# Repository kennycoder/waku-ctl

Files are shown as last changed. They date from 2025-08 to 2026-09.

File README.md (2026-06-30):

# waku-ctl - The open source water cooling controller.

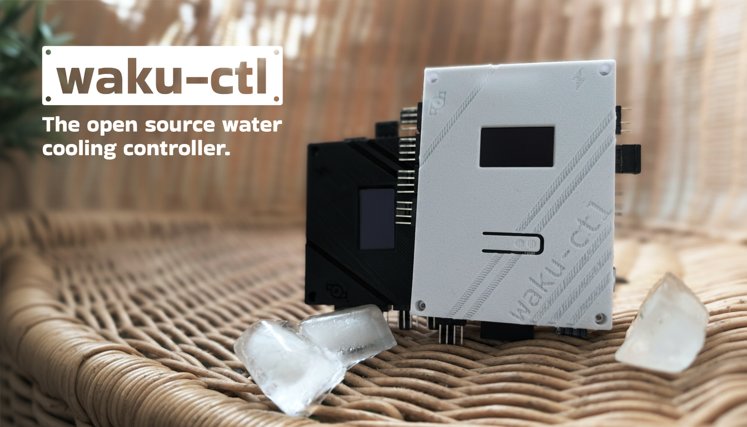
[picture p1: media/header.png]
waku-ctl banner


waku-ctl is an open-source water cooling controller designed to give you ultimate command over your custom water loop, freeing you from the limitations of BIOS profiles and proprietary software.

This project contains the hardware and software for the waku-ctl device.

## Support the Project

If you find waku-ctl useful, please consider supporting its development through a small donation. Your support will help grow the project and bring new features to life!

## How to get an assembled board

I'm happy to assemble a board for you for a fee, just drop me a message via email at me[at]nikolai[dot]one.

## Features

*   **Web Interface:** A user-friendly web interface for configuration and monitoring.
*   **Fan Control:**
    *   Control up to 4 fans/pumps.
    *   Customizable fan curves based on temperature readings.
    *   PID controller for precise temperature management.
    *   Set alarms for fan RPM and temperature thresholds.
    *   Configure step up/down duration for smooth fan speed transitions.
    *   Option to halt the PC on alarm conditions.
*   **Temperature Monitoring:**
    *   Supports three temperature sensors.
    *   Possibility to use deltas between sensors
    *   Display temperatures in Celsius or Fahrenheit.
*   **ARGB Lighting Control:**
    *   Control two separate ARGB headers.
    *   Multiple lighting effects: Static, 2-color wave, 2-color moving, and rainbow.
    *   Pass-through mode from an external ARGB source.
    *   Adjust effect speed and the number of LEDs.
*   **Connectivity:**
    *   WiFi connectivity with support for offline (Access Point) mode.
    *   MQTT support for telemetry data.
    *   USB-CDC daemon for HWiNFO64 integration.
*   **On-device Display:**
    *   OLED screen to display system status, temperatures, fan speeds, and RGB modes.
*   **Hardware:**
    *   Open-source PCB and 3D printable case design.
    *   Based on the powerful ESP32-S3 microcontroller.

## Structure

*   `/pcb`: Contains the PCB design files from Altium.
*   `/case`: Contains the STL files for the 3D printable case.
*   `/src`: Contains the source code for the ESP32 firmware.
*   `/data`: Contains the web interface files.
*   `/usb-cdc-daemon`: Contains a small system tray daemon that reads data via USB and submits it to HWiNFO64.

The firmware is developed using Visual Studio Code with the PlatformIO extension.

## Building the Firmware

1.  Install [Visual Studio Code](https://code.visualstudio.com/).
2.  Install the [PlatformIO IDE extension](https://platformio.org/platformio-ide) from the Visual Studio Code marketplace.
3.  Clone this repository.
4.  Open the cloned repository folder in Visual Studio Code.
5.  PlatformIO will automatically detect the `platformio.ini` file and install the necessary dependencies.
6.  Click the "Build" button in the PlatformIO toolbar (the checkmark icon) to compile the firmware.
7.  Click the "Upload" button (the right arrow icon) to flash the firmware to your connected ESP32-S3 board.
8.  Click "Build Filesystem Image" and "Upload Filesystem Image"
9.  Reset the device and connect to its access point under the name of "waku-ctl" to finish setup.

## Building the USB CDC tray daemon for HWInfo64 integration

1.  Install [golang](https://go.dev/doc/install)
2.  Enter `usb-cdc-daemon` folder and run `go build .`
3.  Execute the binary and check HWInfo64, you should start getting telemetry

### PCB layout

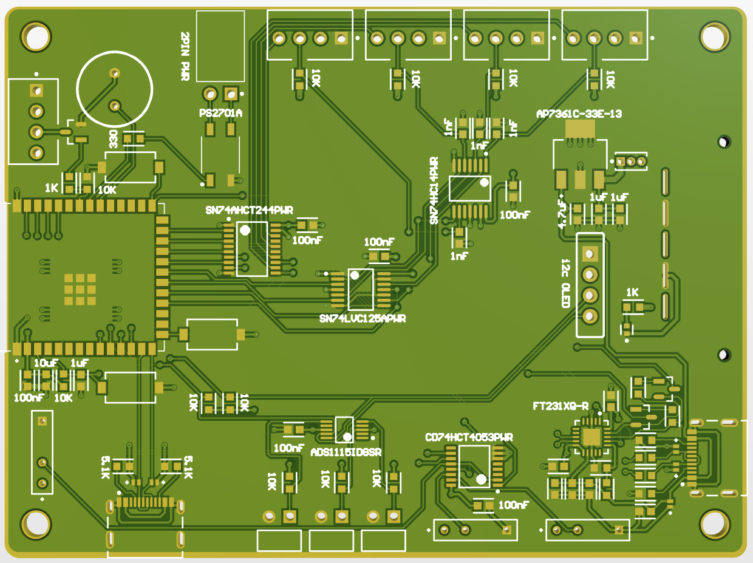
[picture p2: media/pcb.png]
waku-ctl pcb


### PCB schematic

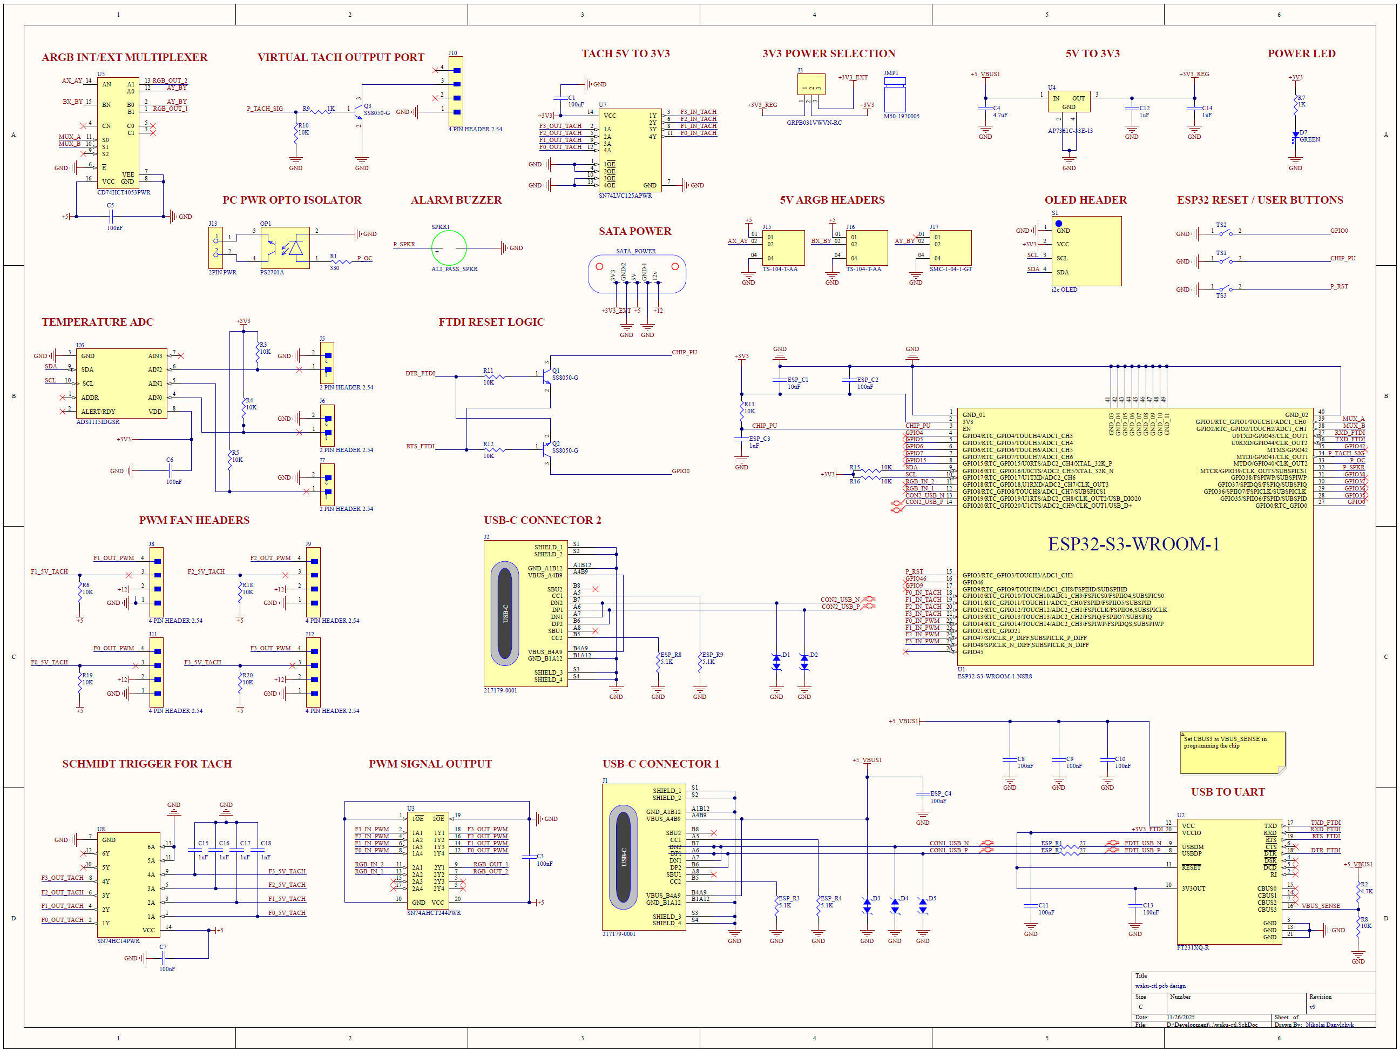
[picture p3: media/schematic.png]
waku-ctl schematic

Also available in [PDF format](media/schematic.pdf).

## UI

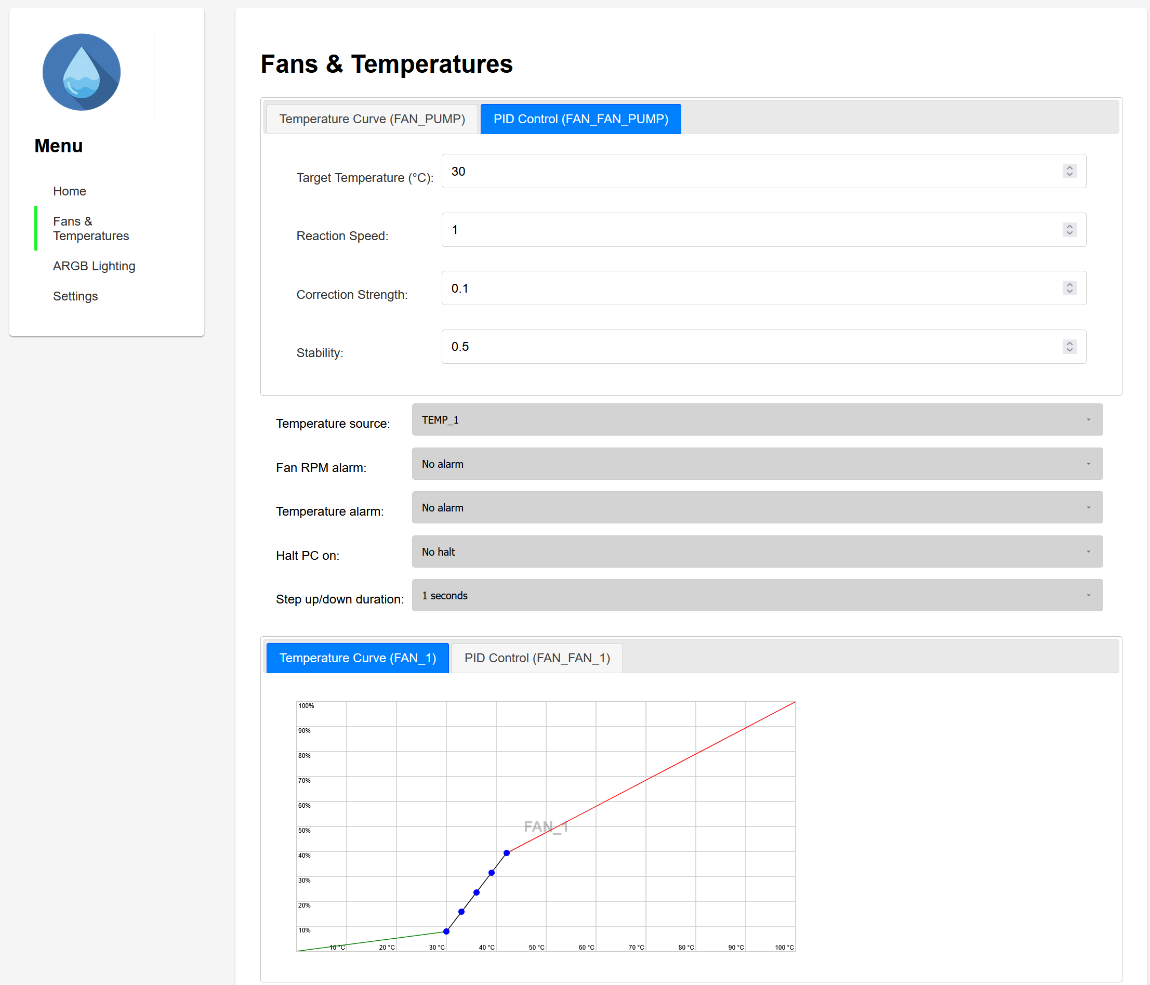
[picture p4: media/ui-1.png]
[](media/ui-1.png)
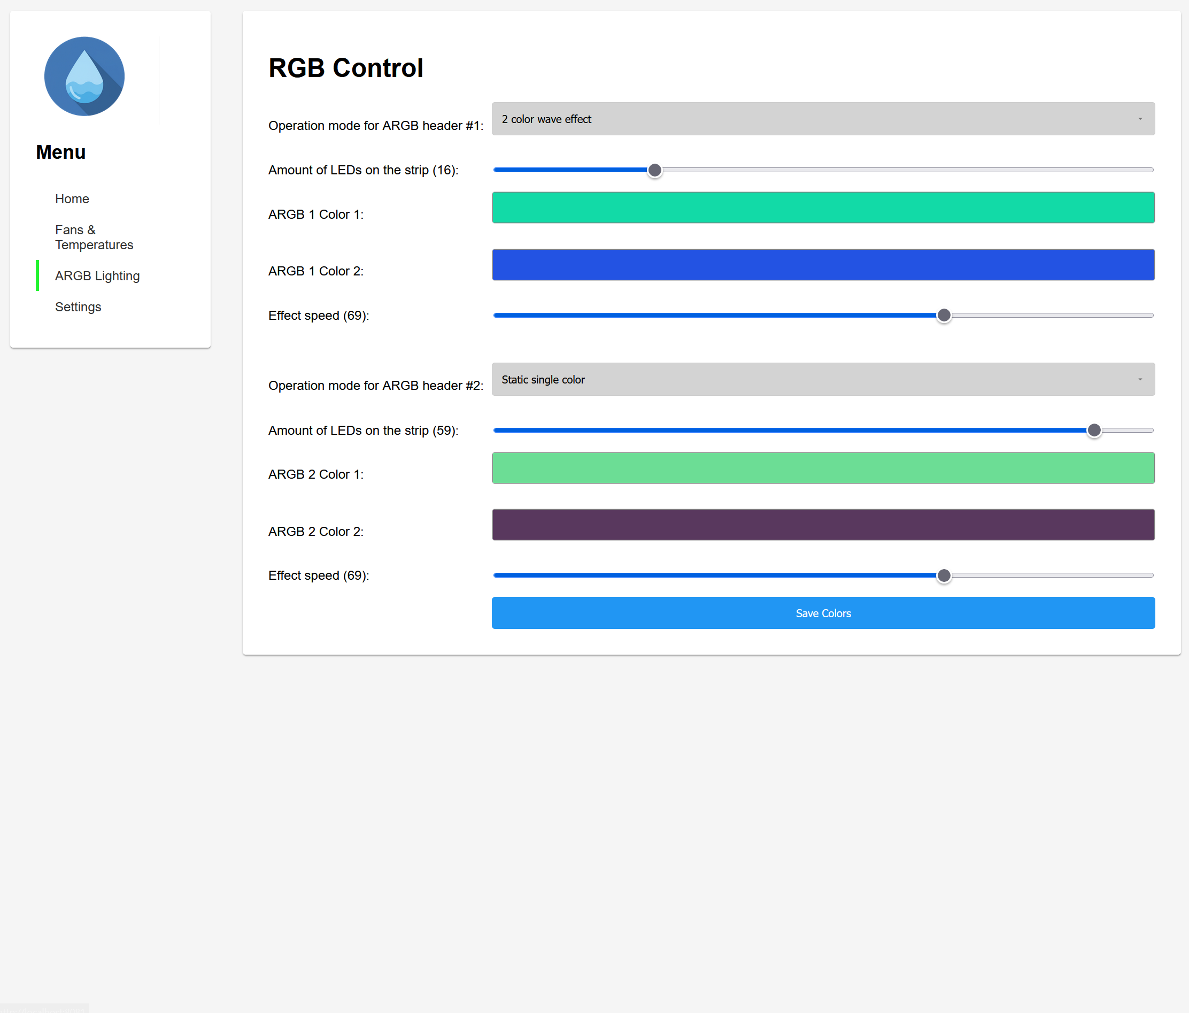
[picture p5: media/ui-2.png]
[](media/ui-2.png)
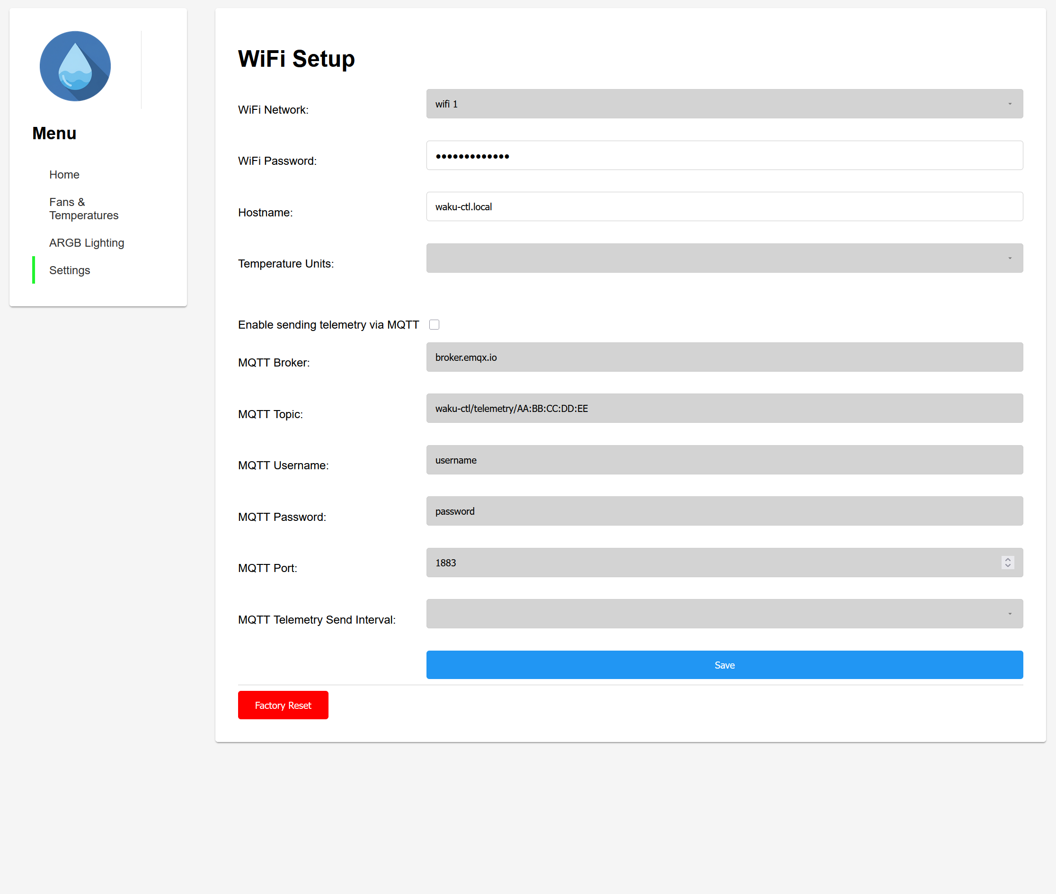
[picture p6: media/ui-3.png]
[](media/ui-2.png)
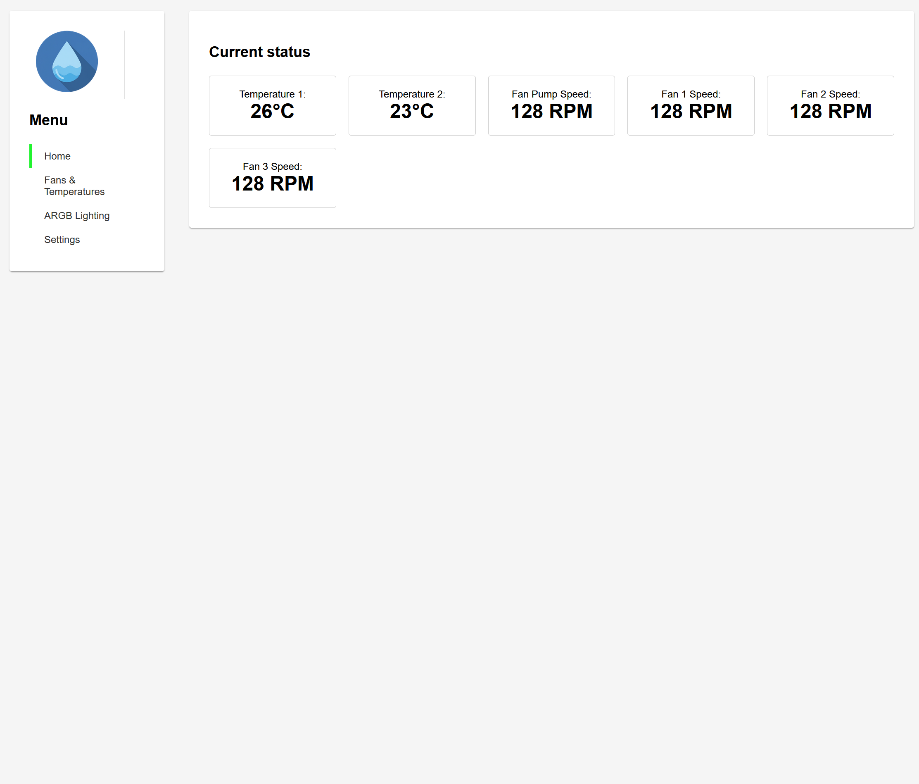
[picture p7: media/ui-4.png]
[](media/ui-2.png)

## Standalone UI

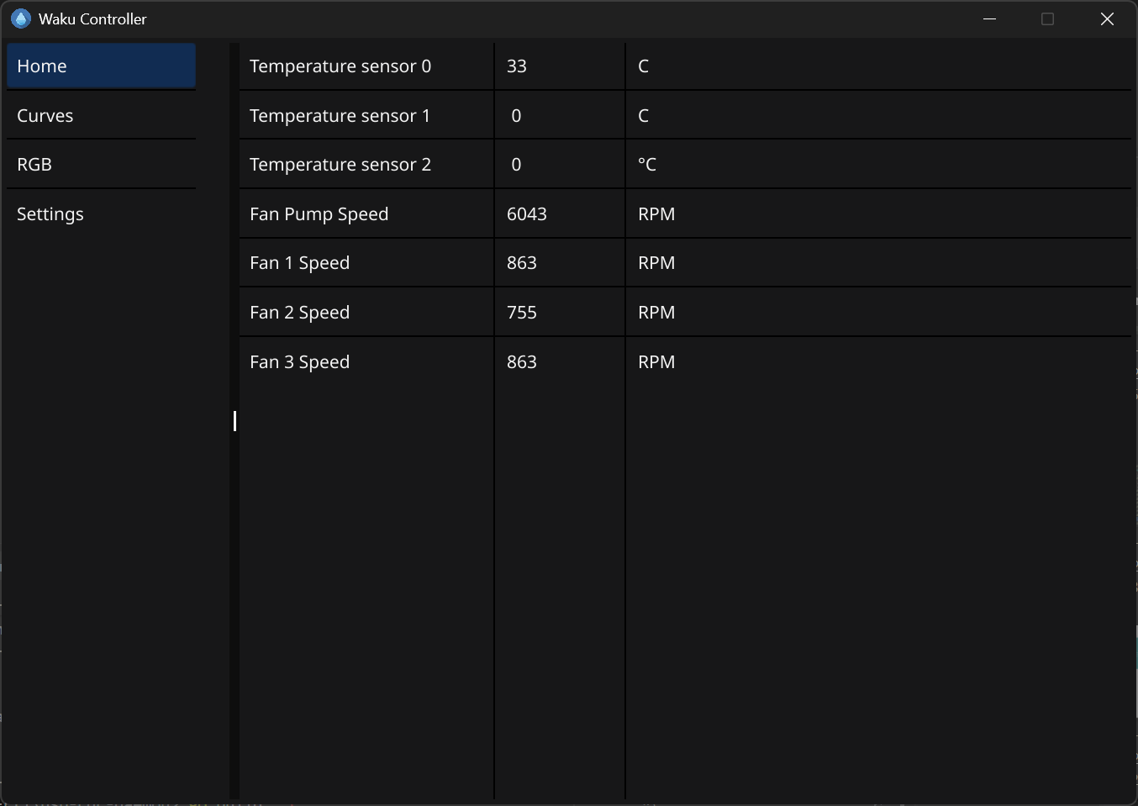
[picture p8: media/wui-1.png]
[](media/wui-1.png)
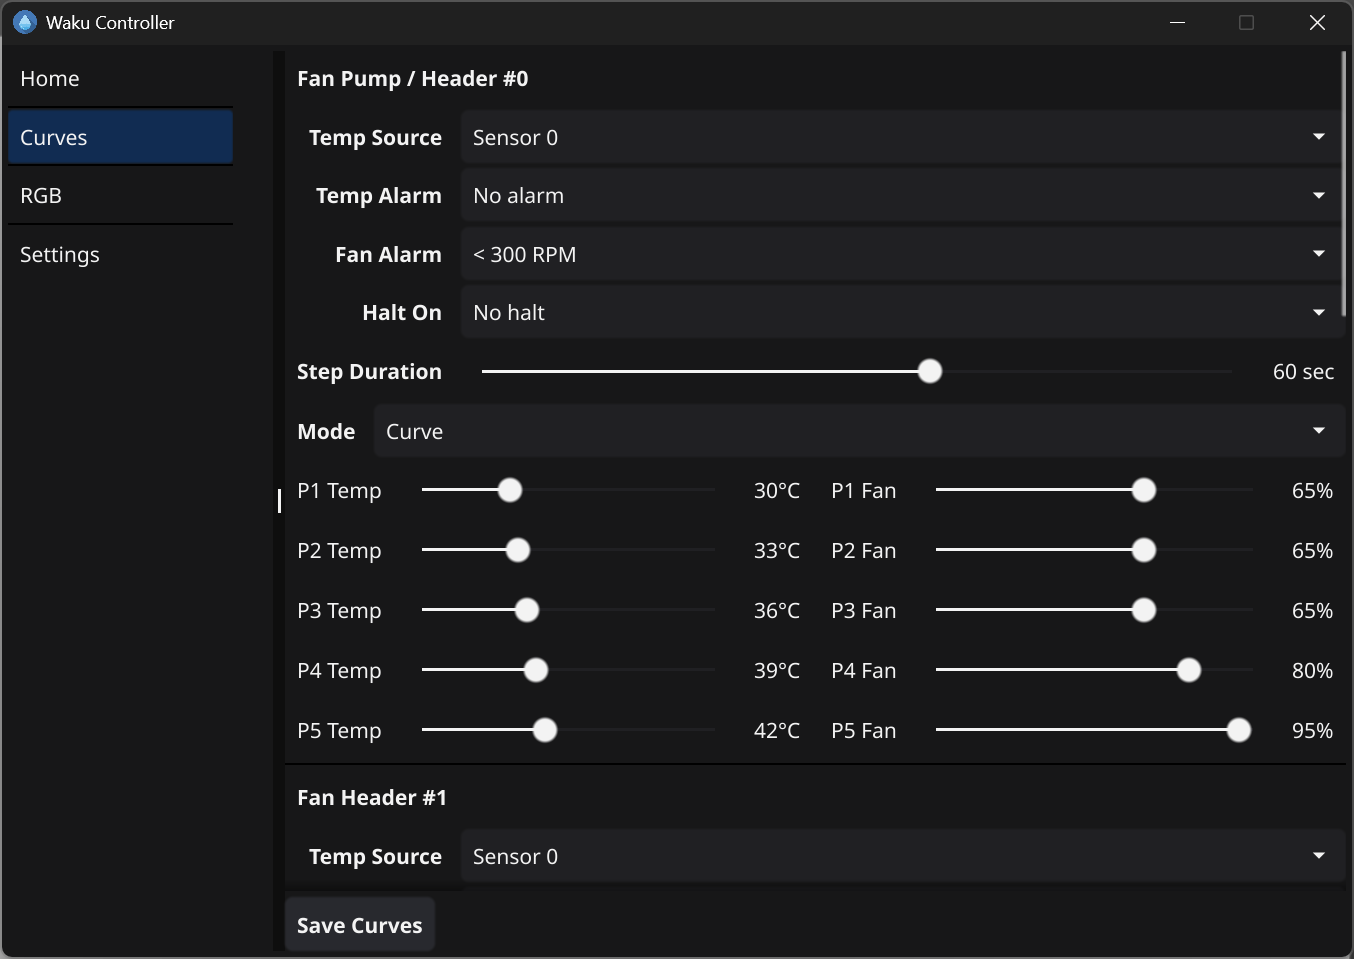
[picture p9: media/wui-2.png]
[](media/wui-2.png)
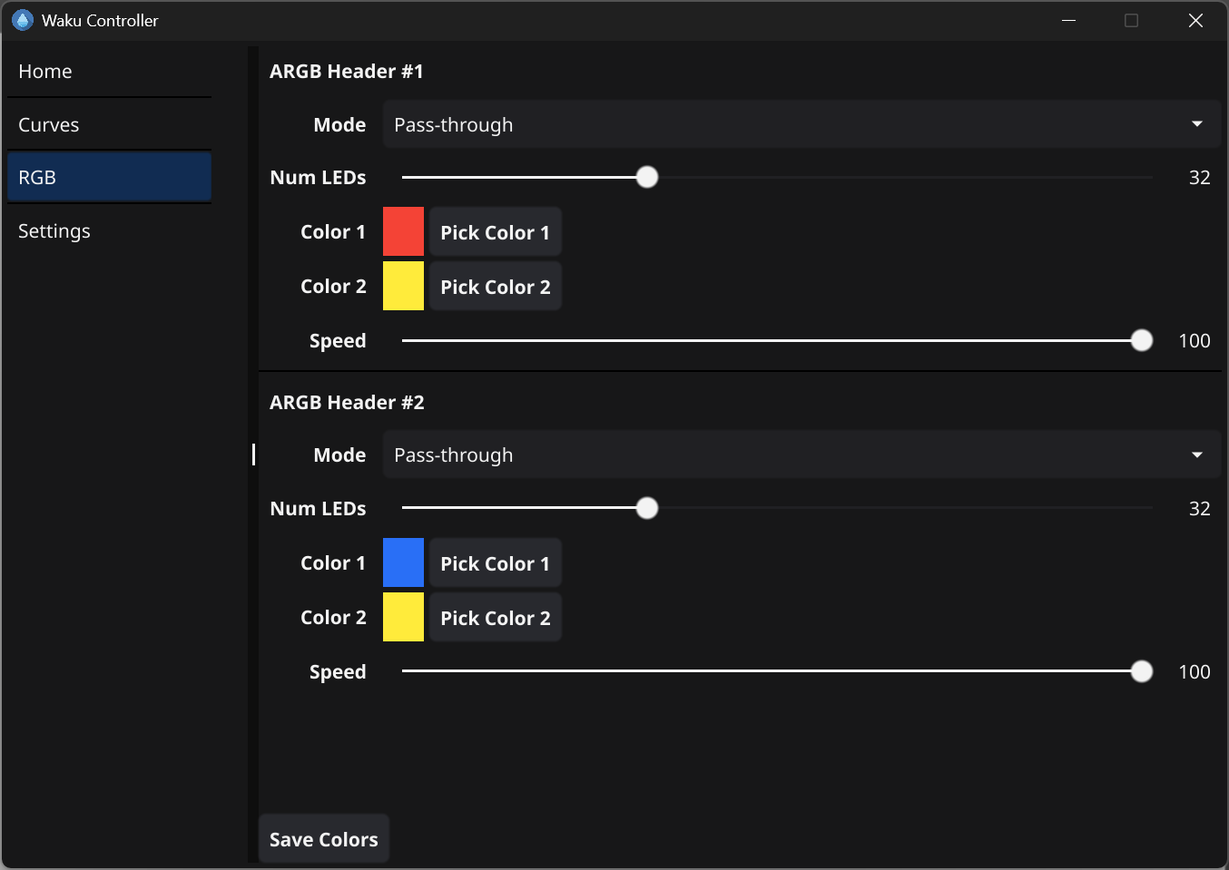
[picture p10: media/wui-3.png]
[](media/wui-2.png)
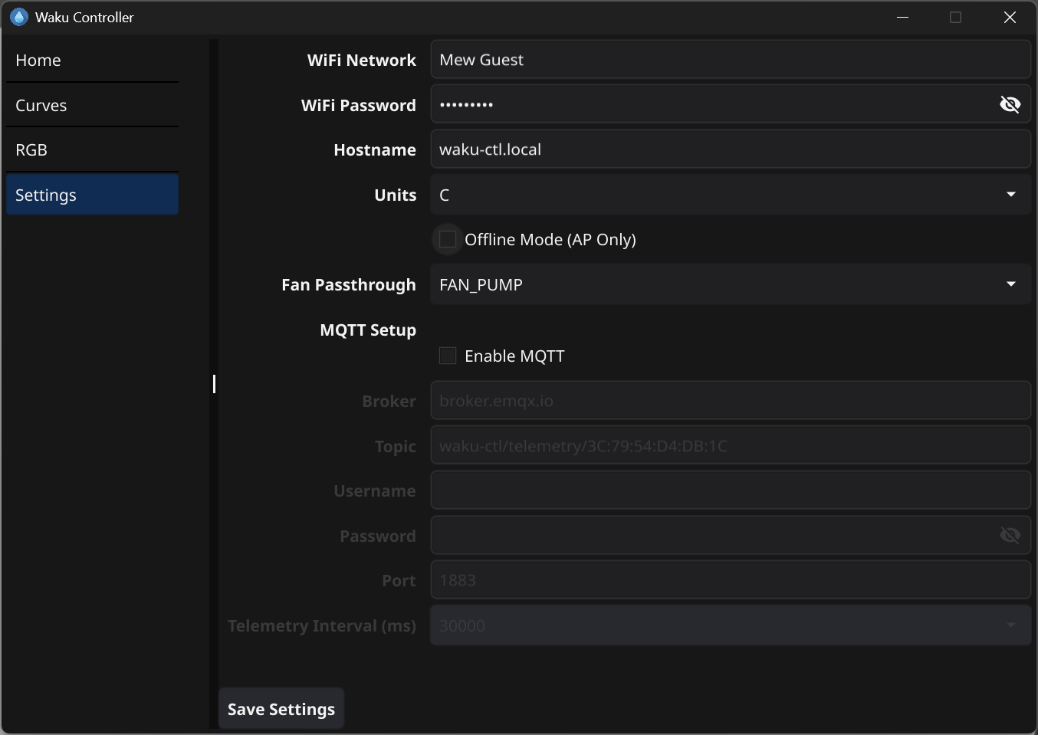
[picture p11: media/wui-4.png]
[](media/wui-2.png)

---

_This project is dedicated to my dad, Alexander Danylchyk who taught me a lot and inspired me to pursue an engineering carrer. You are dearly missed._

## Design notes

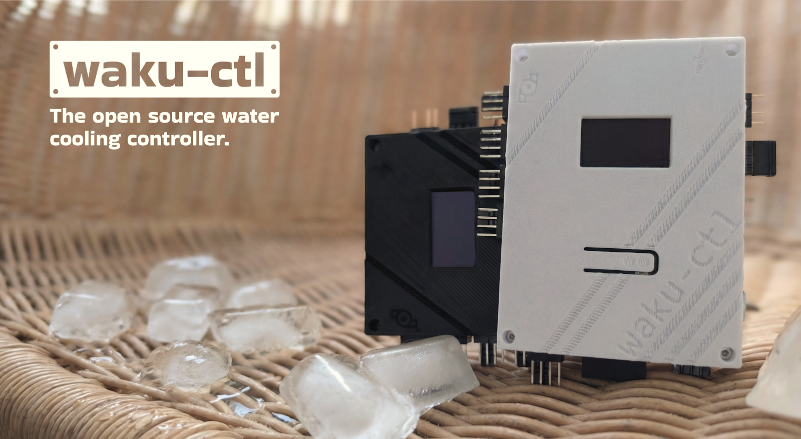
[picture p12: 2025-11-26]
media/header-big.png

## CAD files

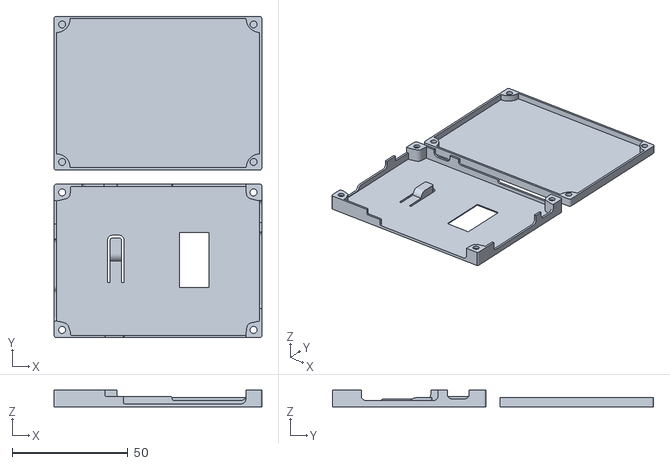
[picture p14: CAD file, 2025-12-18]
case/waku-ctl-full-case.stl
89.8 x 138.8 x 7.30

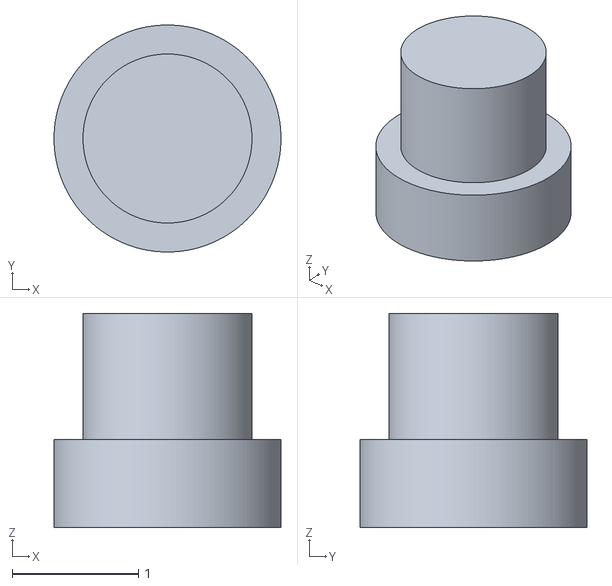
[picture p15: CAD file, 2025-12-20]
case/argb-plug.stl
1.80 x 1.80 x 1.70

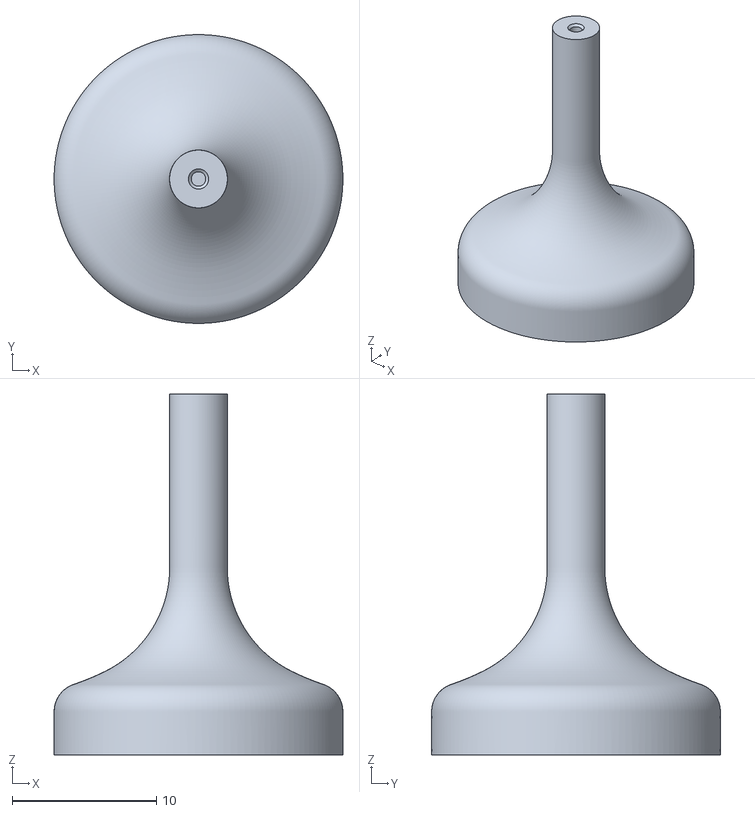
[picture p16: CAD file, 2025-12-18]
case/argb-pin-extractor.stl
20.0 x 20.0 x 25.0

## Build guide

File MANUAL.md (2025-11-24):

# WaKu Controller Board Manual

The **WaKu Controller** is a comprehensive hardware solution for managing custom water-cooling loops and high-performance air-cooled systems. It integrates fan control, pump management, temperature sensing, and ARGB lighting into a single board, with safety features to protect your hardware.

## Hardware Overview

### Power & Connectivity
*   **Power Input**: Powered via a standard **SATA power cable** from your PSU.
*   **Programming/Debug Port**: The **Top USB port** (near the SATA connector) is used for flashing firmware and serial monitoring. It utilizes an FTDI FT231X chip.
*   **Data Port**: The **Side USB port** connects to your PC for software integration (Config Daemon, HWInfo64 data).

### Fan & Pump Headers (Left Side)
There are **4x 4-pin PWM headers** available for fans and pumps.
*   **Pump Header**: The first header is dedicated to the pump (marked with a pump icon on the casing), though it can be used for fans if desired.
*   **Capacity**: Each PWM header can support **3-4 fans** via splitters, depending on their power consumption.
*   **Power Control**: A **2-pin Female Header** is located on this side.
    *   Connect this to your motherboard's Power Switch pins using the provided splitter cable.
    *   This allows the WaKu Controller to physically turn off the PC via optocoupler if a critical alarm triggers.

### Sensors & Lighting (Right Side)
*   **Temperature Sensors**: **3x 2-pin headers** for standard G1/4" 10k thermistors.
    *   *Note: The controller also calculates 3 "Virtual Sensors" representing the delta (difference) between physical sensors.*
*   **ARGB Headers**: **2x 3-pin 5V ARGB headers** for connecting LED strips or components.
    *   Supports up to 96 LEDs per strip (configurable).

### Motherboard Integration (Bottom)
*   **RPM Signal Proxy**: Connects to your motherboard's **CPU_FAN** header.
    *   This sends a simulated RPM signal to your motherboard so it detects a CPU fan is present and running.
    *   You can configure which of the 4 controller fans is proxied to this header.
*   **External ARGB Input**: Connects to an external ARGB controller or motherboard ARGB header.
    *   Allows "Passthrough Mode", letting your motherboard control the LEDs connected to the WaKu Controller.

### Wireless
*   **WiFi**: Integrated ESP32-S3 WiFi.
*   **Antenna**: An IPX connector is available on the board if the signal strength is low inside the case.

---

## Installation & Setup

### 1. Physical Installation
1.  Mount the board in your case.
2.  Connect the **SATA power cable**.
3.  Connect fans and pumps to the PWM headers.
4.  Connect thermistors to the temperature headers.
5.  (Optional) Connect the Power Switch splitter to your motherboard if you want emergency shutdown protection.
6.  (Optional) Connect the Bottom RPM header to your motherboard's CPU_FAN header to avoid BIOS errors.

### 2. Initial Configuration
When first powered on, the controller will create a WiFi Access Point.

1.  On your phone or PC, search for the WiFi network named **`waku-ctl`**.
2.  Connect to it (no password by default).
3.  Open a web browser and navigate to **`http://192.168.4.1`**.
4.  Follow the on-screen instructions to configure your home WiFi credentials and basic settings.
5.  Check the **OLED Screen** on the device for status information (IP address, current mode).

---

## Features & Configuration

### Fan Control
Access the web interface (at the IP shown on the OLED) to configure fan curves.
*   **Modes**:
    *   **Curve**: Set a custom Temperature vs. Duty Cycle (%) curve.
    *   **PID**: Uses a PID algorithm to maintain a specific target temperature.
*   **Sources**: Fans can react to any of the 3 physical temperature sensors or the 3 virtual delta sensors.

### RGB Lighting
*   **Effects**: Static, Gradient Wave, Moving Gradient, Rainbow.
*   **Passthrough**: Select "Passthrough" mode to hand over control to the External ARGB Input header (e.g., for syncing with motherboard software like Aura Sync, Mystic Light).

### Safety & Alarms
The controller monitors system health and can react to failures.
*   **Triggers**:
    *   **High Temp**: Temperature exceeds a defined threshold.
    *   **Low RPM**: Fan/Pump speed drops below a defined threshold.
*   **Actions**:
    *   **Visual/Audio**: The OLED displays the alarm and the onboard buzzer sounds.
    *   **Emergency Shutdown**: If configured, the controller triggers the Power Switch header to immediately shut down the PC to prevent hardware damage.

### OLED Display
The onboard screen cycles through information screens. You can manually cycle screens by pressing the **Reset Button** briefly.
1.  **Overview**: IP, Status, Alarm State.
2.  **Temperatures**: Readings from T1, T2, T3.
3.  **Fan Speeds**: RPM readings for all 4 headers.
4.  **RGB Status**: Current mode for LED strips.

### Reset Button Functions
*   **Short Press**: Cycle OLED screen page.
*   **Long Press (> 5 seconds)**: Factory Reset (clears WiFi and configuration).

---

## Software Integration
*   **Web Interface**: Full control via any browser on the local network.
*   **MQTT**: Supports publishing telemetry to an MQTT broker for integration with Home Assistant or other dashboards.
*   **USB Data**: Connect the Side USB port to use the desktop companion app (Daemon) for integrating sensor data from **HWInfo64** (e.g., controlling fans based on GPU or CPU package temp).

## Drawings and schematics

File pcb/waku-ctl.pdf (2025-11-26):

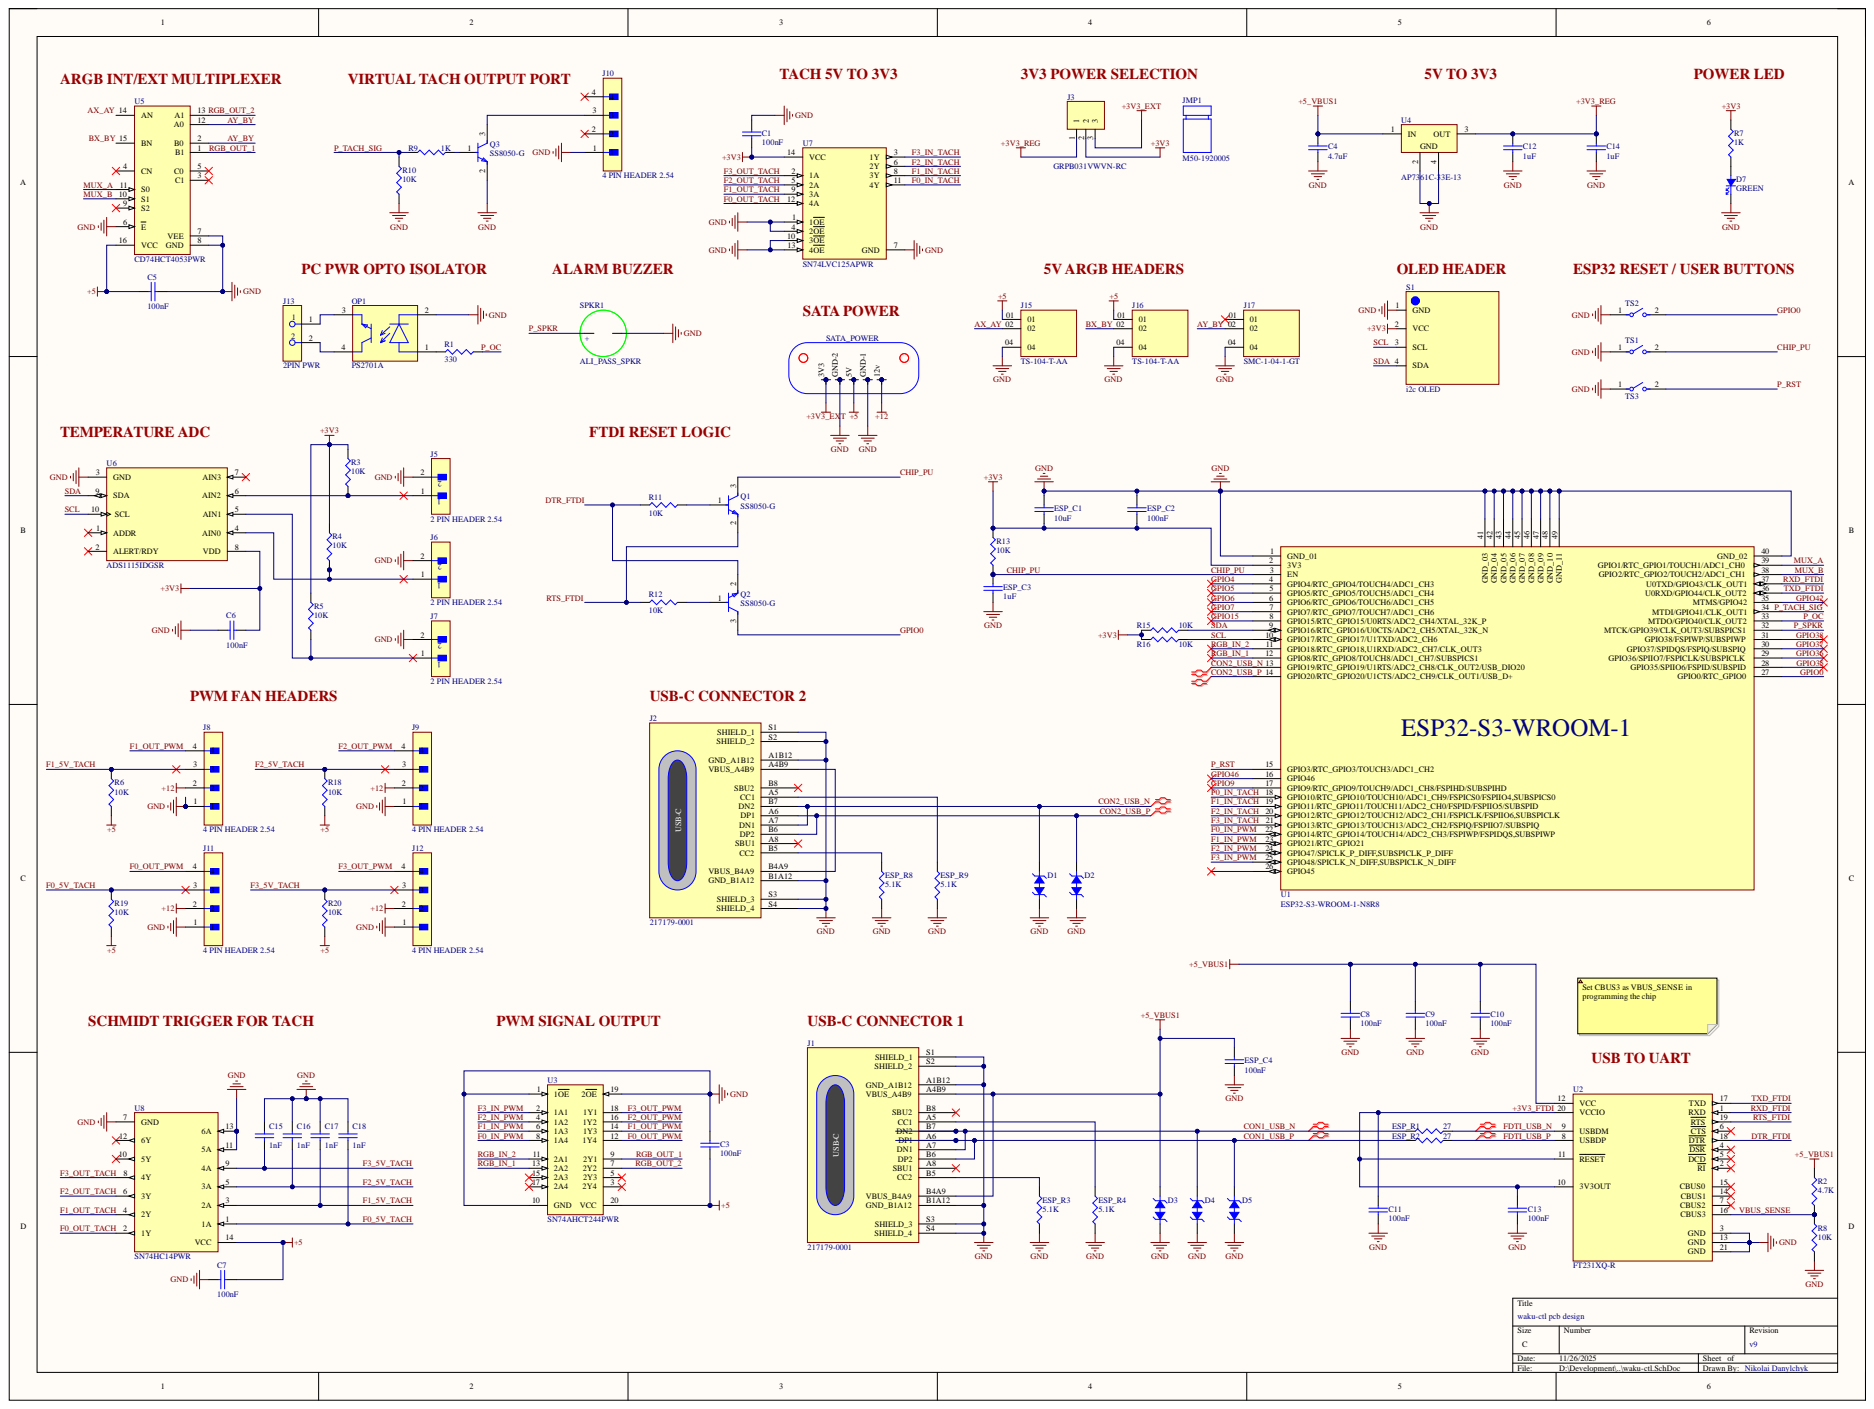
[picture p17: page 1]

ARGB INT/EXT MULTIPLEXER

VIRTUAL TACH OUTPUT PORT

SCHMIDT TRIGGER FOR TACH

waku-ctl pcb design

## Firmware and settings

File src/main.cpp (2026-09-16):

#include "globals.h"
#include "led_manager.h"
#include "mqtt_manager.h"
#include "peripherals_manager.h"
#include "wifi_manager.h"
#include <ElegantOTA.h>
#include <PID_v1.h>
#include <TaskScheduler.h>
#include <Ticker.h>
#include <esp_wifi.h> // Used for mpdu_rx_disable android workaround

enum {
  TUSB_DESC_CONFIG_ATT_REMOTE_WAKEUP = 1u << 5,
  TUSB_DESC_CONFIG_ATT_SELF_POWERED = 1u << 6,
};

Task *gSendTelemetryTask = nullptr;
TaskHandle_t gProcessPIDControllerTaskHandle = NULL;
Scheduler taskScheduler;
Ticker tachTimer;

// --- Function Prototypes ---

// Initialization
void InitializeConfig();
void ClearPreferences();
void SaveConfig(const Settings &s);

void InitializeTasks();
void InitializeHttpServer();
void InitializeFanCurves();

// Core Logic
void setup();
void RunPostSetup();
void loop();

// Tasks
void MonitorButtonTask(void *pvParameters);
void MonitorStatesTask(void *pvParameters);
void ProcessTemperatureCurvesTask(void *pvParameters);
void ProcessPIDControllerTask(void *pvParameters);
void PlayLedsTask(void *pvParameters);
void GenerateTachSignalTask(void *pvParameters);
void DisplayDataTask(void *pvParameters);
void NativeUsbTelemetryTask(void *pvParameters);
void PlayAlarmsTask(void *pvParameters);

String GenerateSettingsJsonString(bool hidePassword = false);


// Telemetry
std::string PrepareTelemetryPayload(const std::string &event = "default");
String GenerateSensorsJson();
void SaveSettingsFromJson(const JsonVariant &json, bool needs_reboot = false);


// HTTP Server
void HandleHttpNotFound(AsyncWebServerRequest *request);
void StreamFile(const String &path, const String &mimetype, bool cache,
                AsyncWebServerRequest *request);

// --- Initialization Functions ---

void InitializeConfig() {
  systemPreferences.begin("config", false);
  if (CLEAR_PREFERENCES_ON_EVERY_BOOT) {
    ClearPreferences();
  }

  uint64_t mac = ESP.getEfuseMac();
  char mac_str[18];
  sprintf(mac_str, "%02X:%02X:%02X:%02X:%02X:%02X", (uint8_t)(mac >> 40),
          (uint8_t)(mac >> 32), (uint8_t)(mac >> 24), (uint8_t)(mac >> 16),
          (uint8_t)(mac >> 8), (uint8_t)(mac));

  espChipIdStr = mac_str;

  systemSettings.ssid = systemPreferences.getString("ssid", "");
  systemSettings.password = systemPreferences.getString("password", "");
  systemSettings.hostname =
      systemPreferences.getString("hostname", "waku-ctl.local");
  systemSettings.telemetry_interval =
      systemPreferences.getInt("tel_itv", TELEMETRY_INTERVAL_MS);
  systemSettings.setup_done = systemPreferences.getBool("setup_done", false);
  systemSettings.offline_mode = systemPreferences.getBool("offline_mode", true);
  systemSettings.units = systemPreferences.getString("units", "C");
  systemSettings.screen_rotation = systemPreferences.getUChar("screen_rot", 0);
  systemSettings.current_screen = systemPreferences.getUChar("curr_screen", 0);
  currentScreen = static_cast<ScreenView>(systemSettings.current_screen);

  systemSettings.mqtt_broker =
      systemPreferences.getString("mqtt_broker", "broker.emqx.io");
  systemSettings.mqtt_enable = systemPreferences.getBool("mqtt_enable", false);
  systemSettings.mqtt_topic = systemPreferences.getString(
      "mqtt_topic", "waku-ctl/telemetry/" + espChipIdStr);
  systemSettings.mqtt_username =
      systemPreferences.getString("mqtt_username", "");
  systemSettings.mqtt_password =
      systemPreferences.getString("mqtt_password", "");
  systemSettings.mqtt_port =
      systemPreferences.getInt("mqtt_port", MQTT_DEFAULT_PORT);
  systemSettings.fan_passthrough =
      systemPreferences.getInt("fan_passthrough", 0);

  Serial.println("Settings loaded.");
}

void SaveConfig(const Settings &s) {
  systemPreferences.putString("ssid", s.ssid);
  systemPreferences.putString("password", s.password);
  systemPreferences.putString("units", s.units);
  systemPreferences.putInt("tel_itv", s.telemetry_interval);
  systemPreferences.putBool("setup_done", s.setup_done);
  systemPreferences.putBool("offline_mode", s.offline_mode);

  systemPreferences.putBool("mqtt_enable", s.mqtt_enable);
  systemPreferences.putString("mqtt_broker", s.mqtt_broker);
  systemPreferences.putString("mqtt_topic", s.mqtt_topic);
  systemPreferences.putString("mqtt_username", s.mqtt_username);
  systemPreferences.putString("mqtt_password", s.mqtt_password);
  systemPreferences.putInt("mqtt_port", s.mqtt_port);
  systemPreferences.putInt("fan_passthrough", s.fan_passthrough);
  systemPreferences.putUChar("screen_rot", s.screen_rotation);
  systemPreferences.putUChar("curr_screen", s.current_screen);
  Serial.println("Settings saved.");
}

void InitializeTasks() {

  xTaskCreate(MonitorStatesTask, "MonitorStates", 4096, NULL, 8, NULL);
  xTaskCreate(ProcessTemperatureCurvesTask, "ReadTemps", 4096, NULL, 7, NULL);
  xTaskCreate(ProcessPIDControllerTask, "ProcessPIDControllerTask", 4096, NULL,
              6, &gProcessPIDControllerTaskHandle);
  xTaskCreate(PlayLedsTask, "PlayLEDs", 4096, NULL, 5, NULL);
  xTaskCreate(DisplayDataTask, "DisplayData", 4096, NULL, 3, NULL);
  xTaskCreate(PlayAlarmsTask, "PlayAlarms", 4096, NULL, tskIDLE_PRIORITY, NULL);

  InitializeMqttTelemetryTask(taskScheduler, gSendTelemetryTask);
  Serial.println("Tasks initialized.");
}

void InitializeFanCurves() {
  for (int fan_id = 0; fan_id < ACTIVE_FANS; fan_id++) {
    String fan_key = "FAN_" + String(fan_id);
    String fan_curves = systemPreferences.getString(fan_key.c_str(), "{}");
    JsonDocument fan_doc;

    Serial.printf("Loading %s - %s\n", fan_key.c_str(), fan_curves.c_str());

    DeserializationError error = deserializeJson(fan_doc, fan_curves);

    if (error || fan_curves == "{}" || fan_curves == "[]") {
      Serial.printf("No/Invalid settings for %s, using defaults.\n",
                    fan_key.c_str());
      m_SensorSettings[fan_id].sensor_id = 0;
      m_SensorSettings[fan_id].temperature_alarm_threshold = 999;
      m_SensorSettings[fan_id].rpm_alarm_threshold = -1;
      m_SensorSettings[fan_id].step_duration_seconds = 1;
      m_SensorSettings[fan_id].fan_speed_curve.push_back(
          {30.0f, MapFanPercentToPwm(30)});
      m_SensorSettings[fan_id].fan_speed_curve.push_back(
          {33.0f, MapFanPercentToPwm(40)});
      m_SensorSettings[fan_id].fan_speed_curve.push_back(
          {36.0f, MapFanPercentToPwm(55)});
      m_SensorSettings[fan_id].fan_speed_curve.push_back(
          {39.0f, MapFanPercentToPwm(75)});
      m_SensorSettings[fan_id].fan_speed_curve.push_back(
          {41.0f, MapFanPercentToPwm(100)});
      m_SensorSettings[fan_id].mode = 0;
      m_SensorSettings[fan_id].pid_kp = 2;
      m_SensorSettings[fan_id].pid_ki = 5;
      m_SensorSettings[fan_id].pid_kd = 1;
      m_SensorSettings[fan_id].min_duty = 51;
      m_SensorSettings[fan_id].max_duty = 255;

      fan_doc["sensor"] = m_SensorSettings[fan_id].sensor_id;
      fan_doc["curves"] = fan_doc.to<JsonArray>();
      for (const auto &setting : m_SensorSettings[fan_id].fan_speed_curve) {
        JsonObject curve_point = fan_doc["curves"].add<JsonObject>();
        curve_point["temp"] = setting.temperature_threshold;
        curve_point["fan"] = setting.fan_duty_cycle;
      }
      fan_doc["temp_th"] = m_SensorSettings[fan_id].temperature_alarm_threshold;
      fan_doc["duty_th"] = m_SensorSettings[fan_id].rpm_alarm_threshold;
      fan_doc["sud_dur"] = m_SensorSettings[fan_id].step_duration_seconds;
      fan_doc["halt_on"] = m_SensorSettings[fan_id].halt_on;
      fan_doc["mode"] = m_SensorSettings[fan_id].mode;
      fan_doc["pid_kp"] = m_SensorSettings[fan_id].pid_kp;
      fan_doc["pid_ki"] = m_SensorSettings[fan_id].pid_ki;
      fan_doc["pid_kd"] = m_SensorSettings[fan_id].pid_kd;
      fan_doc["pid_setpoint"] = m_SensorSettings[fan_id].pid_setpoint;
      fan_doc["min_duty"] = m_SensorSettings[fan_id].min_duty;
      fan_doc["max_duty"] = m_SensorSettings[fan_id].max_duty;

      String settings_json;
      serializeJson(fan_doc, settings_json);
      systemPreferences.putString(fan_key.c_str(), settings_json);
    } else {
      m_SensorSettings[fan_id].sensor_id = fan_doc["sensor"].as<int>();
      m_SensorSettings[fan_id].temperature_alarm_threshold =
          fan_doc["temp_th"].as<int>();
      m_SensorSettings[fan_id].rpm_alarm_threshold =
          fan_doc["duty_th"].as<int>();
      m_SensorSettings[fan_id].step_duration_seconds =
          fan_doc["sud_dur"].as<uint8_t>();
      m_SensorSettings[fan_id].halt_on = fan_doc["halt_on"].as<uint8_t>();
      m_SensorSettings[fan_id].mode = fan_doc["mode"].as<uint8_t>();
      m_SensorSettings[fan_id].pid_kp = fan_doc["pid_kp"].as<double>();
      m_SensorSettings[fan_id].pid_ki = fan_doc["pid_ki"].as<double>();
      m_SensorSettings[fan_id].pid_kd = fan_doc["pid_kd"].as<double>();
      m_SensorSettings[fan_id].pid_setpoint =
          fan_doc["pid_setpoint"].as<double>();
      if (fan_doc["min_duty"].is<uint8_t>()) {
        m_SensorSettings[fan_id].min_duty = fan_doc["min_duty"].as<uint8_t>();
      } else {
        m_SensorSettings[fan_id].min_duty = 51;
      }
      if (fan_doc["max_duty"].is<uint8_t>()) {
        m_SensorSettings[fan_id].max_duty = fan_doc["max_duty"].as<uint8_t>();
      } else {
        m_SensorSettings[fan_id].max_duty = 255;
      }

      m_SensorSettings[fan_id].fan_speed_curve.clear();
      for (auto const &setting : fan_doc["curves"].as<JsonArray>()) {
        m_SensorSettings[fan_id].fan_speed_curve.push_back(
            {setting["temp"].as<float>(), setting["fan"].as<int>()});
      }
    }
  }

  // Set initial fan speeds based on current temps
  for (int fan_id = 0; fan_id < ACTIVE_FANS; fan_id++) {
    const double temp = 25;
    const int target_speed =
        (temp > 0) ? CalculateFanSpeed(fan_id, temp) : MapFanPercentToPwm(25);

    m_TargetFanRpm[fan_id].current_rpm = target_speed;
    m_TargetFanRpm[fan_id].target_rpm = target_speed;
    ledcWrite(PIN_FAN_MAP[fan_id].pwm_pin, target_speed);
  }
}

// --- Core Logic & Tasks ---

void setup() {

  init_globals();
  USB.PID(0x82E5);
  USB.VID(0x303A);
  USB.productName("WaKu Controller");
  USB.manufacturerName("kenny's Labs");
  USB.usbAttributes(TUSB_DESC_CONFIG_ATT_SELF_POWERED |
                    TUSB_DESC_CONFIG_ATT_REMOTE_WAKEUP);
  USBTelemetryPort.begin(115200);
  USB.begin();

  Serial.begin(115200);
  delay(1000); // Wait for serial
  Serial.println("--- WaKu-ctl Booting ---");

  if (!LittleFS.begin(FORMAT_FS_ON_FAIL)) {
    Serial.println("LittleFS Mount Failed!");
    return;
  }
  Serial.println("LittleFS Mounted.");

  Wire.setPins(PIN_SDA, PIN_SCL);
  Wire.begin();

  // Reset button task needs to be started earlier
  xTaskCreate(MonitorButtonTask, "MonitorButton", 4096, NULL, 1, NULL);
  // Same goes for signal passthrough
  xTaskCreate(GenerateTachSignalTask, "GenerateTachSignalTask", 4096, NULL, 4,
              NULL);
  // Same for USB CDC readouts
  xTaskCreate(NativeUsbTelemetryTask, "UsbTelTask", 4096, NULL, 2, NULL);

  InitializeConfig();
  InitializeOutputs();
  InitializeInputs();
  InitializeScreen();
  InitializeWifi();
  InitializeHttpServer();
  

  if (!systemSettings.setup_done) {
    Serial.println(
        "Setup not complete. Waiting for configuration via AP/Web Server.");

    oledDisplay.clearDisplay();
    oledDisplay.setCursor(0, 0);
    oledDisplay.printf("   ### SETUP ###\n\n");
    oledDisplay.printf("SSID: WaKu-ctl\nIP: %s",
                       AP_LOCAL_IP.toString().c_str());
    oledDisplay.display();

    return; // Wait for user to complete setup via web
  }

  RunPostSetup();
  Serial.println("--- WaKu-ctl Ready ---");
}

void RunPostSetup() {
  Serial.println("Running Post-Setup...");
  InitializeMqttClient();
  // InitializeNtpTime(); // Optional, not used for now

  // Make LEDs start immediately, before wifi connects
  InitializeLeds();
  InitializeAdc();
  InitializeFanCurves();
  InitializeTasks();
  b_BootCompleted = true;
  Serial.println("Post-Setup Complete.");
}

void loop() {
  if (b_BootCompleted) {
    taskScheduler.execute();
    LoopMqttClient();

    int t_id = 0;
    for (int i = 0; i < ACTIVE_THERMISTORS; ++i) {
      // IMPORTANT: This is a workaround for a hardware layout where T0 and T1
      // thermistors are swapped on the board.
      // TODO: Fix hardware design in future revisions to avoid this workaround.
      t_id = i;
      if (i == 0)
        t_id = 1;
      else if (i == 1)
        t_id = 0;

      a_currentTemperatures[t_id] = ReadTemperature(i);
    }

    if (ACTIVE_THERMISTORS > 1) {
      int k = 0;
      for (int i = 0; i < ACTIVE_THERMISTORS; ++i) {
        for (int j = i + 1; j < ACTIVE_THERMISTORS; ++j) {
          a_currentTemperatures[ACTIVE_THERMISTORS + k] =
              a_currentTemperatures[j] - a_currentTemperatures[i];
          if (abs(a_currentTemperatures[ACTIVE_THERMISTORS + k]) ==
                  a_currentTemperatures[j] ||
              abs(a_currentTemperatures[ACTIVE_THERMISTORS + k]) ==
                  a_currentTemperatures[i]) {
            a_currentTemperatures[ACTIVE_THERMISTORS + k] = 0;
          }
          // Serial.printf("Delta T%d_T%d: %.2f C\n", a_ThermistorIds[i]+1,
          // a_ThermistorIds[j]+1, a_currentTemperatures[ACTIVE_THERMISTORS +
          // k]);
          k++;
        }
      }
    }

    if (ACTIVE_FANS > 0) {
      for (int fan_id = 0; fan_id < ACTIVE_FANS; ++fan_id) {
        a_CurrentFanSpeedsRpm[fan_id] = ReadFanRpm(fan_id);
      }
    }

    //  Serial.printf("------------\n");
  }

  ElegantOTA.loop();
  vTaskDelay(pdMS_TO_TICKS(250)); // Yield, let tasks run
}

void MonitorButtonTask(void *pvParameters) {
  while (true) {
    // --- Monitor Reset Button ---
    if (digitalRead(PIN_RESET_SETTINGS) == LOW) {
      if (!b_ResetPressed) {
        b_ResetPressed = true;
        gHoldButtonCounter = millis();
        Serial.println("Reset button pressed.");
      } else if (millis() - gHoldButtonCounter >= 5000) {
        // If setup is completed, this button is used to do factory reset
        if (systemSettings.setup_done) {
          Serial.println("Holding > 5s. Clearing preferences & rebooting!");
          ClearPreferences();
          delay(1000);
          esp_restart();
        } else { // Otherwise it's a hack for quick setup
          systemSettings.offline_mode = true;
          systemSettings.ssid = "";
          systemSettings.password = "";
          systemSettings.hostname = "waku-ctl.local";
          systemSettings.setup_done = true;
          systemSettings.telemetry_interval = 30000;
          systemSettings.units = "C";
          b_ResetPressed = false;

          SaveConfig(systemSettings);
          RunPostSetup();
        }
      }
    } else {
      if (b_ResetPressed) { // Button was pressed and now released
        b_ResetPressed = false;
        gHoldButtonCounter = 0;
        if (b_BootCompleted) {
          Serial.println("Reset button released. Cycling screen.");
          // Cycle through screens
          int current_view_int = static_cast<int>(currentScreen);
          current_view_int = (current_view_int + 1) % 5; // 5 screens total
          currentScreen = static_cast<ScreenView>(current_view_int);
        }
      }
    }
    vTaskDelay(pdMS_TO_TICKS(50)); // Check ~4 times a second
  }
}

void MonitorStatesTask(void *pvParameters) {
  unsigned long task_start_time = millis();
  bool boot_delay_completed = false;
  while (true) {
    if (!boot_delay_completed && millis() - task_start_time > 3000) {
      boot_delay_completed = true;
    }

    // --- Monitor Alarms ---
    bool temp_alarm_active = false;
    bool rpm_alarm_active = false;

    for (int fan_id = 0; fan_id < ACTIVE_FANS; ++fan_id) {
      const auto &settings = m_SensorSettings[fan_id];

      const double temp = a_currentTemperatures[settings.sensor_id];
      const unsigned long current_rpm = a_CurrentFanSpeedsRpm[fan_id];

      // Temperature Alarm
      if (temp > 0 && settings.temperature_alarm_threshold > 0 &&
          temp >= settings.temperature_alarm_threshold) {
        if (settings.halt_on == HALT_ON_ALARM_TEMP ||
            settings.halt_on == HALT_ON_ALARM_BOTH) {
          Serial.println("Halting system due to alarm condition.");
          digitalWrite(PIN_PWR, HIGH); // Cut power
        }
        temp_alarm_active = true;
        if (!b_TempAlarmFiring)
          Serial.printf("ALARM: Temp high on %s (%.1fC)\n", settings.sensor_id,
                        temp);
      }

      // RPM Alarm (only if threshold is set, >= 0, and 3 seconds have passed
      // since boot)
      if (boot_delay_completed && settings.rpm_alarm_threshold >= 0 &&
          current_rpm < (unsigned long)settings.rpm_alarm_threshold) {
        if (settings.halt_on == HALT_ON_ALARM_FAN ||
            settings.halt_on == HALT_ON_ALARM_BOTH) {
          Serial.println("Halting system due to alarm condition.");
          digitalWrite(PIN_PWR, HIGH); // Cut power
        }
        rpm_alarm_active = true;
        if (!b_RpmAlarmFiring)
          Serial.printf("ALARM: RPM low on FAN_%d (%lu RPM)\n", fan_id,
                        current_rpm);
      }
    }

    b_TempAlarmFiring = temp_alarm_active;
    b_RpmAlarmFiring = rpm_alarm_active;

    vTaskDelay(pdMS_TO_TICKS(250)); // Check ~4 times a second
  }
}

void PlayAlarmsTask(void *pvParameters) {
  while (true) {
    if (b_TempAlarmFiring || b_RpmAlarmFiring) {
      // Play sound (Beep pattern)
      tone(PIN_BUZZER, b_TempAlarmFiring ? 1000 : 4000, 500);
      vTaskDelay(pdMS_TO_TICKS(1000));
      b_TempAlarmStopped = false;
    } else {
      if (!b_TempAlarmStopped) {
        noTone(PIN_BUZZER);
        digitalWrite(PIN_PWR,
                     LOW); // Stop cutting power (if cutting), alarm turned off.
        b_TempAlarmStopped = true;
      }
      vTaskDelay(pdMS_TO_TICKS(250));
    }
  }
}

void ProcessTemperatureCurvesTask(void *pvParameters) {
  while (true) {

    if (DEBUG_ENABLED && DEBUG_DATA_ENABLED) {
      for (int i = 0; i < ACTIVE_THERMISTORS; ++i) {
        Serial.printf("T%d: %.2f C; ", i + 1, a_currentTemperatures[i]);
      }
      Serial.printf("\n");
    }

    for (int fan_id = 0; fan_id < ACTIVE_FANS; ++fan_id) {

      if (m_SensorSettings[fan_id].mode == 1) { // Only run if in curve mode
        continue;                               // Skip to next fan
      }

      const auto &settings = m_SensorSettings[fan_id];
      const double temp = a_currentTemperatures[settings.sensor_id];

      if (temp <= 0) {
        if (DEBUG_ENABLED && DEBUG_DATA_ENABLED)
          Serial.printf("Temp sensor N/A for FAN_%d. Skipping.\n", fan_id);
        continue; // Skip if temp sensor not working/connected
      }

      auto &target = m_TargetFanRpm[fan_id];
      int new_target_pwm = CalculateFanSpeed(fan_id, temp);

      if (new_target_pwm != target.target_rpm && !target.is_adjusting) {
        target.target_rpm = new_target_pwm;
        target.step_value = (target.target_rpm - target.current_rpm) /
                            settings.step_duration_seconds;
        if (target.step_value == 0 && target.target_rpm != target.current_rpm) {
          target.step_value = (target.target_rpm > target.current_rpm) ? 1 : -1;
        }

        if (target.step_value != 0) {
          target.start_time_ms = millis();
          target.is_adjusting = true;
          Serial.printf("FAN_%d: Adjusting %d -> %d (Step: %d)\n", fan_id,
                        target.current_rpm, target.target_rpm,
                        target.step_value);
        } else {
          target.current_rpm = target.target_rpm; // No change needed
        }
      }

      if (target.is_adjusting && (millis() - target.start_time_ms >= 1000)) {
        target.start_time_ms = millis();
        target.current_rpm += target.step_value;

        // Clamp and check if target reached
        bool reached = false;
        if (target.step_value > 0 && target.current_rpm >= target.target_rpm) {
          target.current_rpm = target.target_rpm;
          reached = true;
        } else if (target.step_value < 0 &&
                   target.current_rpm <= target.target_rpm) {
          target.current_rpm = target.target_rpm;
          reached = true;
        }

        if (reached) {
          Serial.printf("FAN_%d: Reached target %d\n", fan_id,
                        target.target_rpm);
          target.is_adjusting = false;
        }
        if (m_CurrentFanPwmValues[fan_id] != target.current_rpm) {
          ledcWrite(PIN_FAN_MAP[fan_id].pwm_pin, target.current_rpm);
          m_CurrentFanPwmValues[fan_id] = target.current_rpm;
        }

      } else if (!target.is_adjusting) {
        // Ensure it stays at target if not adjusting
        if (m_CurrentFanPwmValues[fan_id] != target.target_rpm) {
          ledcWrite(PIN_FAN_MAP[fan_id].pwm_pin, target.target_rpm);
          m_CurrentFanPwmValues[fan_id] = target.target_rpm;
        }
      }

      if (DEBUG_ENABLED && DEBUG_DATA_ENABLED) {
        Serial.printf("FAN_%d RPM: %lu (Target PWM: %d, Current PWM: %d)\n",
                      fan_id, a_CurrentFanSpeedsRpm[fan_id], target.target_rpm,
                      target.current_rpm);
      }
    }
    vTaskDelay(pdMS_TO_TICKS(250)); // Read temps/adjust fans twice a second
  }
}
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

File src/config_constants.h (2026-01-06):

#ifndef CONFIG_CONSTANTS_H
#define CONFIG_CONSTANTS_H

// --- MQTT ---
constexpr int MQTT_DEFAULT_PORT = 1883;
constexpr int MQTT_CLIENT_BUFFER_SIZE = 10240;
constexpr int MQTT_SOCKET_TIMEOUT_SECS = 60;

// --- System Behaviour ---
constexpr bool FORMAT_FS_ON_FAIL = true;
constexpr bool DEBUG_ENABLED = true;
constexpr bool DEBUG_MQTT_ENABLED = true;
constexpr bool DEBUG_DATA_ENABLED = false;
constexpr unsigned long TELEMETRY_INTERVAL_MS = 30000;
constexpr bool CLEAR_PREFERENCES_ON_EVERY_BOOT = false;

// --- Screen ---
constexpr int SCREEN_WIDTH = 128;     // OLED display width, in pixels
constexpr int SCREEN_HEIGHT = 64;     // OLED display height, in pixels
constexpr uint8_t SCREEN_ADDR = 0x3C; // 0x3D for 128x64, 0x3C for 128x32

// --- Thermistor Control ---
constexpr int T_REFERENCE_RESISTANCE = 10000;
constexpr int T_NOMINAL_RESISTANCE = 10000;
constexpr int T_NOMINAL_TEMPERATURE = 25;
constexpr int T_B_VALUE = 3950;
constexpr int ESP32_ANALOG_RESOLUTION = 4095;
constexpr double ADC_VOLTAGE = 3.3;

// --- Fan Control ---
constexpr unsigned long FAN_DEBOUNCE_MICROS = 5000; // Microseconds
constexpr int PWM_RESOLUTION_BITS = 8;
constexpr int PWM_SIGNAL_FREQUENCY_HZ = 25000; // Hz
constexpr int TACH_PWM_CHANNEL = 15;

// --- LED Control ---
constexpr int ACTIVE_LED_STRIPS = 2;
constexpr int MAX_LEDS_PER_STRIP = 128;

// --- Hardware Counts ---
constexpr int ACTIVE_THERMISTORS = 3;
constexpr int ACTIVE_THERMISTORS_DELTAS =
    (ACTIVE_THERMISTORS * (ACTIVE_THERMISTORS - 1)) / 2;
constexpr int ACTIVE_THERMISTORS_WITH_DELTAS =
    ACTIVE_THERMISTORS + ACTIVE_THERMISTORS_DELTAS;
constexpr int ACTIVE_FANS = 4;

// --- Other Constants ---
constexpr int HALT_ON_ALARM_NONE = 0;
constexpr int HALT_ON_ALARM_FAN = 1;
constexpr int HALT_ON_ALARM_TEMP = 2;
constexpr int HALT_ON_ALARM_BOTH = 3;

#endif // CONFIG_CONSTANTS_H

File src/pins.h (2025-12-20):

#include "types.h"

#ifndef PINS_H
#define PINS_H

#include <Arduino.h>

// --- System Pins ---
constexpr uint8_t PIN_RESET_SETTINGS = 3;
constexpr uint8_t PIN_BUZZER = 39;
constexpr uint8_t PIN_PWR = 38; // Power control
constexpr uint8_t PIN_TACH = 41; // Simulated tach input for motherboard header

// --- I2C / Screen Pins ---
constexpr int8_t PIN_SDA = 16; // GPIO8 as I2C SDA
constexpr int8_t PIN_SCL = 17; // GPIO9 as I2C SCL
constexpr int8_t PIN_OLED_RESET = -1; // Reset pin # (-1 if sharing Arduino reset pin)

// --- LED Pins ---
constexpr uint8_t PIN_LED_HEADER_1 = 8; // LED header #1 Data
constexpr uint8_t PIN_LED_HEADER_2 = 18; // LED header #2 Data

constexpr uint8_t PIN_LED_EXT_CTRL_1 = 1; // LED header #1 External Control | MUX A
constexpr uint8_t PIN_LED_EXT_CTRL_2 = 2; // LED header #2 External Control | MUX B

// --- Fan Pins ---
extern std::map<int, FanPinPair> PIN_FAN_MAP;

#endif // PINS_H

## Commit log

2025-08-20 Initial waku-ctl release
    [Ali-Speaker.PcbLib, Ali-Speaker.SchLib, SATA-Power.PcbLib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]
2025-08-20 Added PCB view
2025-08-28 reduced unnecessary readings from ADC
2025-08-28 Fixed minor issues with FAN_2 and FAN_3
    [waku-ctl-board.PrjPcb, waku-ctl.PcbDoc, waku-ctl.SchDoc]
2025-08-28 Updated polling interval for reading button press state
2025-09-01 Added PID functionality
2025-09-01 Updated case to v2
    [waku-ctl-case.stl]
2025-09-02 Fixed PID controls and target direction. Added new tab styles
    [main.cpp]
2025-09-02 Updated PCB for 3 inputs
    [waku-ctl-board.PrjPcb, waku-ctl.PcbDoc, waku-ctl.SchDoc]
2025-09-02 Updated BOM and CPL files
    [bom.csv, waku-ctl-board.PrjPcb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]
2025-09-03 Fixed to use isnan method instead of == NAN
    [main.cpp]
2025-09-17 Fixed missing resistor
    [bom.csv, waku-ctl-board.PrjPcb, waku-ctl.PcbDoc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]
2025-09-27 Added tach emulator for pump passthrough. Fixes on PWM channels. Removal of USB CDC task since it needs rework
    [waku-ctl-bottom.stl, waku-ctl-top.stl, waku-ctl.PcbDoc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]
2025-09-28 Added a possible of passthrough of another fan to motherboard header. UI changes. Removal of jquery ui tabs. Bugfixes
    [config_constants.h, main.cpp, peripherals_manager.cpp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]
2025-09-29 Reworking fan and temp ids
    [config_constants.h, main.cpp, peripherals_manager.cpp]
2025-10-02 Minor fixes to OLED display
    [main.cpp, pins.h]
2025-10-02 Updated PCB design with routing tweaks and overall cleanup
    [waku-ctl-board.PrjPcb, waku-ctl.PcbDoc, waku-ctl.SchDoc]
2025-10-04 Updated how temperatures and fans are displated. Added deltas for calculations
    [ESP32-S3-WROOM-1.SchLib, waku-ctl-board.PrjPcb]
2025-10-08 new pcb layout
    [Ali-Speaker.SchLib, ESP32-S3-WROOM-1.PcbLib, ESP32-S3-WROOM-1.SchLib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]
2025-10-09 Full PCB with backup
    [Ali-Speaker.PcbLib, ESP32-S3-WROOM-1.PcbLib, SATA-Power.PcbLib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]
2025-10-12 new-pcb pre-release test
    [ESP32-S3-WROOM-1.PcbLib, ESP32-S3-WROOM-1.SchLib, waku-ctl-board.PrjPcb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]
2025-10-26 Working tach generation on new PCB
2025-10-28 Updated board schematic and libs for new layout. Fixes to some orientation and temp header ids
    [ESP32-S3-WROOM-1.PcbLib, ESP32-S3-WROOM-1.SchLib, waku-ctl-board.PrjPcb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]
2025-10-30 new pcb with internal FDTI chip
    [ESP32-S3-WROOM-1.PcbLib, ESP32-S3-WROOM-1.SchLib, waku-ctl-board.PrjPcb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]
2025-10-31 Fixed PWM signal issues
    [ESP32-S3-WROOM-1.PcbLib, ESP32-S3-WROOM-1.SchLib, waku-ctl-board.PrjPcb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]
2025-11-03 Updated PCB with jumper for USB-C 3v3 power
    [ESP32-S3-WROOM-1.PcbLib, ESP32-S3-WROOM-1.SchLib, waku-ctl.PcbDoc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]
2025-11-11 Final touches for pre-release v2
    [waku-ctl.PcbDoc, waku-ctl.SchDoc]
2025-11-11 updated net name for GPIO_0
    [waku-ctl.PcbDoc, waku-ctl.SchDoc]
2025-11-18 Updates to the board and board library
    [ESP32-S3-WROOM-1.PcbLib, ESP32-S3-WROOM-1.SchLib, waku-ctl.PcbDoc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]
2025-11-22 Fixes to delta calculations and reworked tach signal generation via open collector
    [ESP32-S3-WROOM-1.SchLib, waku-ctl-board.PrjPcb, waku-ctl.PcbDoc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]
2025-11-22 Updated PCB with non TTL Schmitt trigger since it's not needed
    [waku-ctl.PcbDoc, waku-ctl.SchDoc]
2025-11-24 reworked pcb v1'
    [ESP32-S3-WROOM-1.PcbLib, ESP32-S3-WROOM-1.SchLib, waku-ctl.PcbDoc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]
2025-11-24 changed TXS0104E to something better
    [ESP32-S3-WROOM-1.SchLib, waku-ctl.PcbDoc, waku-ctl.SchDoc]
2025-11-25 Minor updates to 3v3 rail on the pcb
    [ESP32-S3-WROOM-1.PcbLib, ESP32-S3-WROOM-1.SchLib, waku-ctl.PcbDoc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]
2025-11-26 Finalized new prototype
    [waku-ctl-board.PrjPcb, waku-ctl.PcbDoc, waku-ctl.SchDoc]
2025-11-26 remove irrelevant bom and cpl files
    [bom.csv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]
2025-12-13 Updated spacing for SATA connector and minor task fixes
    [ESP32-S3-WROOM-1.PcbLib, waku-ctl-board.PrjPcb, waku-ctl.PcbDoc]
2025-12-18 Minor board fixes + new case STL
    [argb-pin-extractor.stl, waku-ctl-board.PrjPcb, waku-ctl-bottom.stl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]
2025-12-20 Swapped GPIO40 pin on opto coupler to avoid shutting down during flash
    [argb-plug.stl, waku-ctl.PcbDoc, waku-ctl.SchDoc]
2025-12-22 Working basic prototype
2025-12-23 Fixed C/F values in PID control over wifi
2025-12-23 Added ElegantOTA for updates
    [partitions_8mb_ota.csv]
2026-01-06 Updated UI, OTA, LED bugfixes
    [config_constants.h, led_manager.cpp, main.cpp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]
2026-01-11 Added copy fan curves feature
2026-01-13 Added fallback when WiFi doesn't connect
    [main.cpp, wifi_manager.cpp]
2026-03-05 Fixed labels and texts in the UI
    [waku-ctl-board.PrjPcb, waku-ctl.PcbDoc]
2026-09-12 Added PID control with visual config
2026-09-16 Fixes in setup and reset of the post-setup command
    [main.cpp]
